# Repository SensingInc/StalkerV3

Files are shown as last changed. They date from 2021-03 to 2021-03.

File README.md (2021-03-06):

# StalkerV3
Repository for development of the Stalker stem strength tester.

## Introduction
The Stalker is an instrument for measuring stalk or stem strength in plants. Its development, building, and use is outlined in this HardwareX paper: https://www.sciencedirect.com/science/article/pii/S2468067218301184

and its data analysis (and theory of operation) is outlined in this Applied Sciences paper: https://www.mdpi.com/2076-3417/10/22/7965

The bill of materials can be found here: https://docs.google.com/spreadsheets/d/1YpdJ8Psb1IhpG5ddTsx0BFufkG1ZGOrEwDEdpia4aTM/edit?usp=sharing

## Contents
This repository contains the firmware (Stalkerv3B.ino) and the schematic (MainBoard.sch) and board (MainBoard.brd) files to build and program the internals of the latest version of the Stalker.

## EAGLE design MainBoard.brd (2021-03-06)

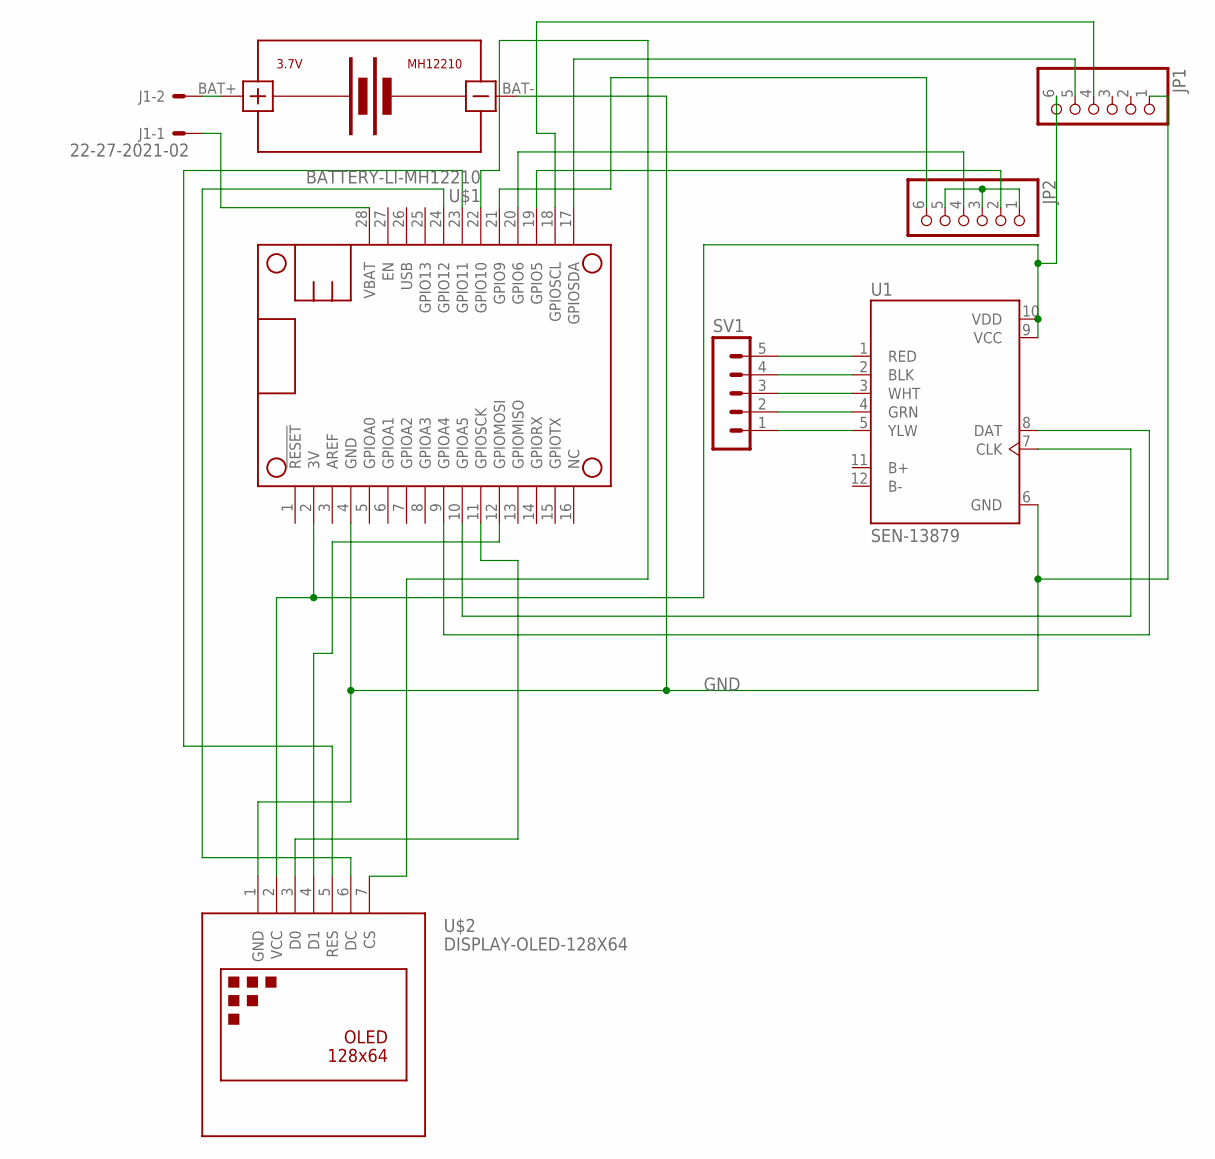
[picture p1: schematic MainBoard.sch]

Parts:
J1: 22-27-2021-02; 6410-02
JP1, JP2: PINHD-1X6; 1X06
MS1: FEATHERWING_NODIM; FEATHERWING_DIM
SV1: MA05-1
U1: SEN-13879; SPARKFUN_SEN-13879
U$1: BATTERY-LI-MH12210
U$2: DISPLAY-OLED-128X64

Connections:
3V: JP1.6, MS1.2 (3V), U1.9 (VCC), U1.10 (VDD), U$2.2 (VCC)
GND: JP1.1, MS1.4 (GND), U1.6 (GND), U$1.BAT-, U$2.1 (GND)
unnamed: JP2.2, MS1.19 (GPIO5)
unnamed: MS1.9 (GPIOA4), U1.8 (DAT)
unnamed: MS1.10 (GPIOA5), U1.7 (CLK)
unnamed: J1.2, U$1.BAT+
unnamed: SV1.1, U1.5 (YLW)
unnamed: SV1.2, U1.4 (GRN)
unnamed: SV1.3, U1.3 (WHT)
unnamed: JP2.4, MS1.20 (GPIO6)
unnamed: JP2.6, MS1.21 (GPIO9)
unnamed: MS1.22 (GPIO10), U$2.7 (CS)
unnamed: MS1.11 (GPIOSCK), U$2.3 (D0)
unnamed: MS1.12 (GPIOMOSI), U$2.4 (D1)
unnamed: MS1.23 (GPIO11), U$2.5 (RES)
unnamed: MS1.24 (GPIO12), U$2.6 (DC)
unnamed: SV1.4, U1.2 (BLK)
unnamed: SV1.5, U1.1 (RED)
unnamed: JP1.4, MS1.18 (GPIOSCL)
unnamed: JP2.1, JP2.3, JP2.5
SDA: JP1.5, MS1.17 (GPIOSDA)
VBAT: J1.1, MS1.28 (VBAT)

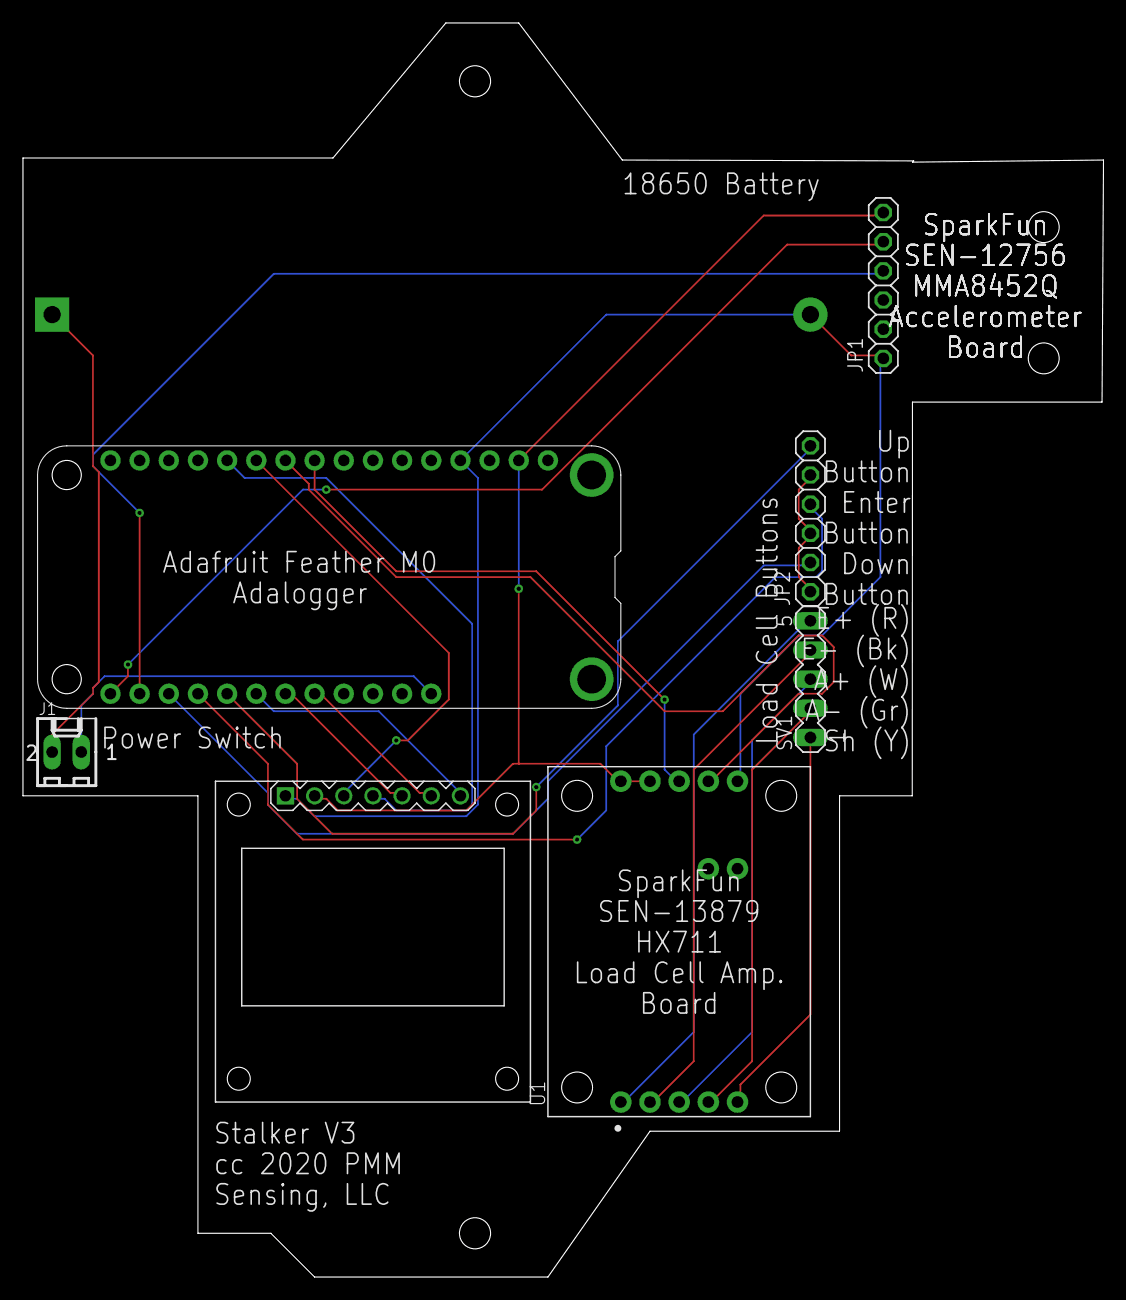
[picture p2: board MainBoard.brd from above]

Board: 2 copper layers, 94.1 x 109.2 mm, 8 parts (1 on the bottom side), 22 nets.

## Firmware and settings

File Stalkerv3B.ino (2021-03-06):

// for adalogger m0

#define PREFIX_LENGTH 5 //Define the filename prefix length
#define SCREEN_DIM 128  //Define the pixel count of the OLED screen rows
#define SCLK_P 24 //Define the pin for the SPI clock
#define MOSI_P 23 //Define the pin for the SPI MOSI port
#define DC_P 12 //Define the DC pin for the SPI OLED screen
#define CS_P 10 //Define the CS pin for the SPI OLED screen
#define RST_P 11  //Define the reset pin for the SPI OLED screen
#define LOAD_DATA A4  //Define the data pin for the HX711 load cell ADC
#define LOAD_CLK A5 //Define the clock pin for the HX711 load cell ADC
#define BLACK 0x0000  //Define the screen color for black in 8 bytes
#define WHITE 0xFFFF  //Define the screen color for white in 8 bytes

#include <stdlib.h> //Include the standard library
#include <avr/dtostrf.h>  //Include the double to string function library
#include <U8x8lib.h>  //Include the OLED screen library
#include <SPI.h>  //Include the SPI library
#include <Wire.h> //Include the Wire (I2C) library
#include <SD.h> //Include the SD library
#include <SparkFun_MMA8452Q.h>  //Include the accelerometer library
#include <HX711_ADC.h>  //Include the load cell ADC library
#include <RTCZero.h>

U8X8_SH1106_128X64_NONAME_4W_HW_SPI tft(/* cs=*/ CS_P, /* dc=*/ DC_P, /* reset=*/ RST_P); //Create a screen instance
MMA8452Q accel;   //Create an accelerometer instance
HX711_ADC LoadCell(LOAD_DATA, LOAD_CLK);  //Create a load cell ADC instance
File file;
RTCZero rtc;

int hours = 0;
int minutes = 0;
int seconds = 0;
int day = 3;
int month = 3;
int year = 21;
int up=5; //Create a button instance for the up button
int down=6; //Create a button instance for the down button
int sel=9; //Create a button instance for the sel button
int file_num = 0; //Create a count integer to hold number of files
long start_time=0;
String PREFIX = "S002"; //Create a string to hold the prefix
String compileDate = (__DATE__);
String compileTime = (__TIME__);

void setup() {  //Enter the setup function
  Serial.begin(9600);
  rtc.begin();
  hours = compileTime.substring(0, 2).toInt();    // convert hours to an int
  minutes = compileTime.substring(3, 5).toInt();  // convert minutes to an int
  seconds = compileTime.substring(6, 8).toInt();  // convert seconds to an int
  rtc.setDate(day, month, year);
  rtc.setTime(hours, minutes, seconds);
  pinMode(up, INPUT_PULLUP);
  pinMode(down, INPUT_PULLUP);
  pinMode(sel, INPUT_PULLUP);
  accel.init(); //Initialize the accelerometer instance
  accel.read(); //Read the accelerometer
  LoadCell.begin(); //Initialize the load cell ADC instance
  LoadCell.start(10); //Start communications with the load cell ADC
  LoadCell.setCalFactor(696.0); //Set the load cell ADC calibration gain factor
  attachInterrupt(LOAD_DATA, ISR, FALLING); //Attach an interrupt to the load cell ADC data pin
  tft.begin();  //Initialize the screen
  tft.setFont(u8x8_font_chroma48medium8_r); //Set the font for use on the screen
  if (!SD.begin(4)) { //Initialize the SD card instance, and if it doesn't start correctly
    tft.setCursor(0, 0);  //Set the cursor on the screen to the top left corner
    tft.println("SD ERR");  //Write "SD ERR" to the screen
    while (1); //And hang until reset
  }
  while (SD.exists(PREFIX + String(file_num) + ".csv")) file_num++;
  file = SD.open(PREFIX + String(file_num) + ".csv", FILE_WRITE);
  file.println("date,time,angle (°),force (arbs)"); //Add a header line to the file with the three output variable names
  delay(500);
  start_time = millis(); //Create a long called start_time and set it to the current number of msec at the start of sampling
}

void loop() { //Enter the loop function
  tft.setCursor(0,0);
  if(rtc.getHours() < 10){
    tft.print('0');
  }
  tft.print(rtc.getHours());
  tft.print(':');
  if(rtc.getMinutes() < 10){
    tft.print('0');
  }
  tft.print(rtc.getMinutes());
  tft.print(':');
  tft.println(rtc.getSeconds());
  delay(100);
  accel.read(); //Read the accelerometer
  double angle; //Create a double variable called angle
  long cur_time = 0;  //Create a long called cur_time to store current time
  float force = 0;  //Create a float called force to store the current force from the load cell
  char angle_str[7];  //Create a char array of 7 characters called angle_str to store the angle in string form
  char force_str[8];  //Create a char array of 8 characters called force_str to store the force in string form
  angle = 90.*accel.z / 1024.;  //Set angle equal to the normalized acceleration mapped to degrees
  angle = abs(angle); //Take the absolute value of angle
  dtostrf(angle, 6, 1, angle_str);  //Create a string in the char array angle_str to store the angle
  force = LoadCell.getData(); //Set force equal to the data coming back from the load cell
  dtostrf(force, 7, 1, force_str);  //Create a string in the char array force_str to store the angle
  cur_time = millis() - start_time; //Set cur_time as the current time from millis() minus the start time in msec
    file.print(rtc.getDay());
  file.print("/");
  file.print(rtc.getMonth());
  file.print("/");
  file.print(rtc.getYear()+2000);
  file.print(",");
  file.print(rtc.getHours());
  file.print(":");
  if(rtc.getMinutes() < 10)
    file.print('0');      // Trick to add leading zero for formatting
  file.print(rtc.getMinutes());
  file.print(":");
  if(rtc.getSeconds() < 10)
    file.print('0');      // Trick to add leading zero for formatting
  file.print(rtc.getSeconds());
  file.print(",");  //Print a comma into the data file
  file.print(angle_str);  //Print the angle_str variable into the data file
  file.print(",");  //Print a comma into the data file
  file.println(force_str);  //Print the force_str variable into the data file
  tft.print(PREFIX);
  tft.println(file_num);
  tft.print("Angle: ");
  tft.println(angle_str); //Print the angle on the screen
  tft.print("Force: ");
  tft.println(force_str); //Print a line with the force on the screen
  tft.print(cur_time / 1000); //Print the current time in sec
  tft.println(" s"); //Print a line saying " s" on the screen
  file.flush();
}

void ISR() {  //Enter the ISR function for assigning the interrupt service
  LoadCell.update();  //Update data from the load cell ADC
}

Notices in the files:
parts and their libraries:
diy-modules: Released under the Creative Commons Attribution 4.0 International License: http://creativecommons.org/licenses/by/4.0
